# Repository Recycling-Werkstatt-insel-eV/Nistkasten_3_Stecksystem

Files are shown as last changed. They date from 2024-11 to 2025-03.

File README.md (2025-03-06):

# Vogelhaus Nr. 3

Bei diesem Vogelhaus ist der Zusammenbau ein Kinderspiel. Es werden kaum Schrauben und kein Klebstoff benötigt. Fast alle Teile werden zusammengsteckt und sind austauschbar, je nachdem welche Vogelart ihr bei euch findet. Der gesamte Entwurf besteht aus nachhaltigen und/oder recycelbaren und wiederverwendbaren Materialien. Auch der integrierte Raubtierschutz und die einfache Reinigungsmöglichkeit machen eure Vögel zu glücklichen Mieter_innen!

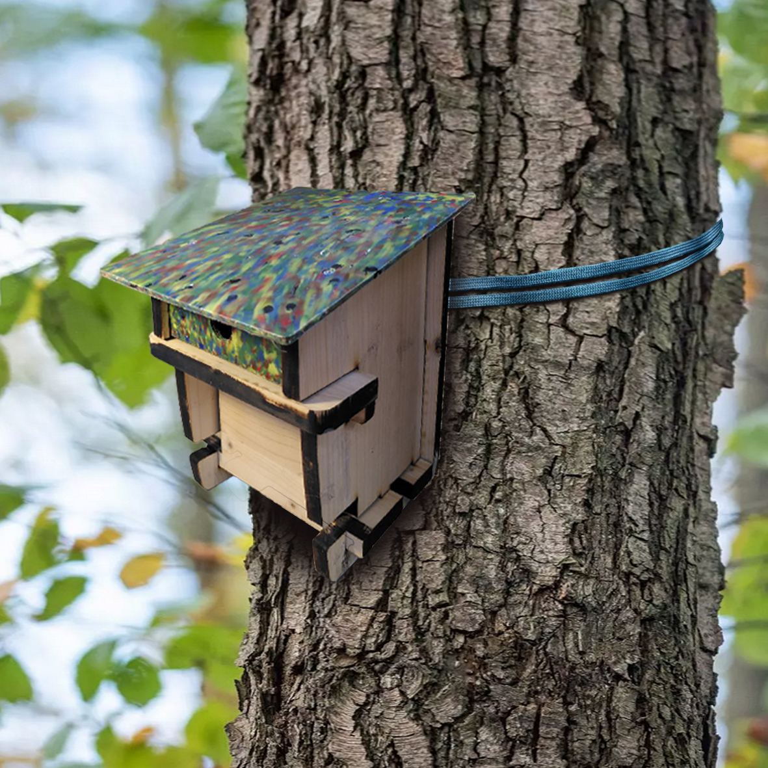
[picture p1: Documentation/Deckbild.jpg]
 

__Du möchtest dieses Vogelhaus bauen?__

Dann ist es sinnvoll, dass du dich in folgender Reihenfolge durch das Projekt manövrierst: 
Zu Beginn solltest du dir die allgemeine [Checkliste](./Documentation/Checkliste.md) anschauen um dir einen geeigneten Einstieg in das Projekt zu geben. Welche Materialien du überhaupt benötigst erfährst du in der [Materialliste](./Drawings/Materialliste_Vogelhaus_Stecksystem.pdf). Anschließend kannst du dich der [Fertigung der Einzelteile](./Documentation/Anleitung_Fertigung.md) widmen, die wenn du sie sorgsam beachtest, den [Zusammenbau](./Documentation/Anleitung_Zusammenbau.md) erleichtern wird. 
Solltest du dieses Vogelhaus noch weiterentwickeln wollen, stehen dir außerdem noch eine [CAD Datei im Step-Format](./CAD/CAD_Stecksystem_Vogelhaus.STEP) und die entsprechenden [Technischen Zeichnungen](./Drawings/Vogelhaus_Stecksystem_Technische_Zeichnungen.pdf) zur Verfügung.

# Allgemeines zum Projekt

Bei diesem Vogelhaus handelt es sich um einen von __4 Entwürfen__ aus einer Reihe innerhalb eines Projekts, in dem wir uns zur Aufgabe gemacht haben, kreative innovative und nachhaltige Ideen für Tierbehausungen zu finden und alte Lösungen zu überdenken. Unseren Fokus haben wir auf Vogelbehausungen gelegt. Und wer sind "wir"? Wir sind Menschen aus der Offenen [Recycling-Werkstatt von Insel e.V.](https://werkstatt.insel-ev.de/) in Hamburg. Besucht uns gerne auf unserer Website oder noch besser persönlich, wir freuen uns auf euch! 

Hier kommt ihr zur [Übersicht](https://github.com/Recycling-Werkstatt-insel-eV/Nistkasten_main_Uebersicht) der folgenden Entwürfe
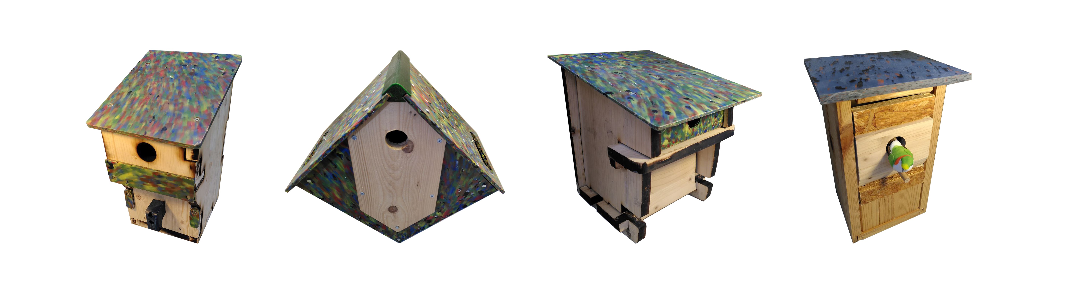
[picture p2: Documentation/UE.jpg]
 
Gefördert von der [Deutschen Stiftung Engagement und Ehrenamt](https://www.deutsche-stiftung-engagement-und-ehrenamt.de/foerderung/) haben wir im Laufe des Jahres 2024 zusammen mit Schüler_innen-Gruppen, Expert_innen vom [NABU](https://www.nabu.de/) und anderen klugen Köpfen getüftelt, wie wir Zeiten, in denen die Umwelt und Natur so schutzbedürftig wie noch nie sind, einen sinnvollen Beitrag leisten können. In Ideen- und Bau- Workshops sind dabei schlussendlich die 4 Konzepte entstanden und umgesetzt worden, die wir euch hier vorstellen wollen. 

__Und was macht unsere Entwürfe besonders?__
Besonders wichtig war uns unter anderem, dass die verwendeten Materialien möglichst nachhaltig sind und eingesetzt werden. Das heißt sie sollen wenig oder gar nicht neu produziert werden müssen. Wir wollen mit Dingen arbeiten, die es schon gibt und diese wieder aufbereiten und neu verwenden. Dafür haben wir in jedem Entwurf recycelten Kunststoff aus unserer Werkstatt verwendet. Dieser besteht aus geschredderten, geschmolzenen zu Platten gepressten Alltagsgegenständen, die sonst in den Müll gewandert wären. Außerdem sind alle Bestandtteile wieder voneinander trennbar. Es wurden keine Klebstoffe und nur wenige Schrauben verwendet. Modulare Systeme ermöglichen zusätzlich das Austauschen und ersetzen einzelner Bestandtteile, sodass die Vogelhäuser leicht repariert werden können und teilweise mehrere Funktionen und Varianten in einem Entwurf beinhalten.  

Aber wie das halt so ist... Kein Entwurf ist perfekt durchdacht. Und genau da kommt ihr ins Spiel. Wir wollen unser Projekt der Community zur Verfügung stellen und euch herzlich einladen die Vogelhäuser __nachzubauen, oder sogar weiterzuentwickeln__. Die Informationen, die  ihr genau dafür benötigt und wie ihr Schritt für Schritt vorgeht, findet ihr in den beiligenden Vogelhaus-Projekten. Von eher unkomplizierten Ideen, die mit einfachen Handwerkzeugen gefertigt werden können, bis hin zu gelaserten oder CNC- gefrästen z.T. herausfordernden Systemen ist für jede_n etwas dabei. Alles kann nichts muss und das gilt auch für die euch zur Verfügung stehenden Mittel. Von uns kommen einige gut gemeinte Ratschläge für die Umsetzung, fühlt euch jedoch gerne frei manches im Sinn eurer Möglichkeiten anders zu machen. Schaut euch gerne um ob und welches Vogelhaus etwas für euch ist, viel Spaß beim bauen und weiterdenken!

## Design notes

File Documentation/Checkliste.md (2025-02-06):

# Checkliste

Unabhängig davon ob ihr eines der Vogelhäuser nachbaut, weiterentwickelt oder einen ganz neuen Entwurf kreiren und aufhängen wollt, gibt es einige wichtige Dinge zu beachten, die für die Umwelt, die Tiere und den Erfolg des Projekts mehr oder weniger wichtig sein können. 
Hier findet ihr eine Übersicht an Checkpunkten an denen wir uns oriententiert haben. 

__Schutz vor Nesträubern__

Viele Tierarten, insbesondere Vögel sind heutzutage stark bedroht. Neben anderen Faktoren sind Nesträuber wie Waschbären, Marder und Hauskatzen dafür verantwortwortlich. Um zu verhindern, dass diese Tiere die Brut der Singvögel bedrohen gibt es bewährte Maßnahmen:

1. Gestalte die Einflugöffnung gerade so groß, dass nur der Nistvogel und vergleichbargroße Arten durchpassen.
2. Baue einen vorgezogenen Zwischenboden in das Vogelhaus, (so wie wir es z.B. bei den Vogelhäusern "Stecksystem" und "Oskar" gemacht haben).
   In dieser Form haben die Räuber Schwierigkeiten bis zur Brut hinunter zu greifen. 
4. Bringe den Vogelkasten idealerweise in einer Höhe von mindestens 2 Metern an, sodass es manchen Räubern schwerer fällt die Brut zu wittern und 
diese zu erreichen.

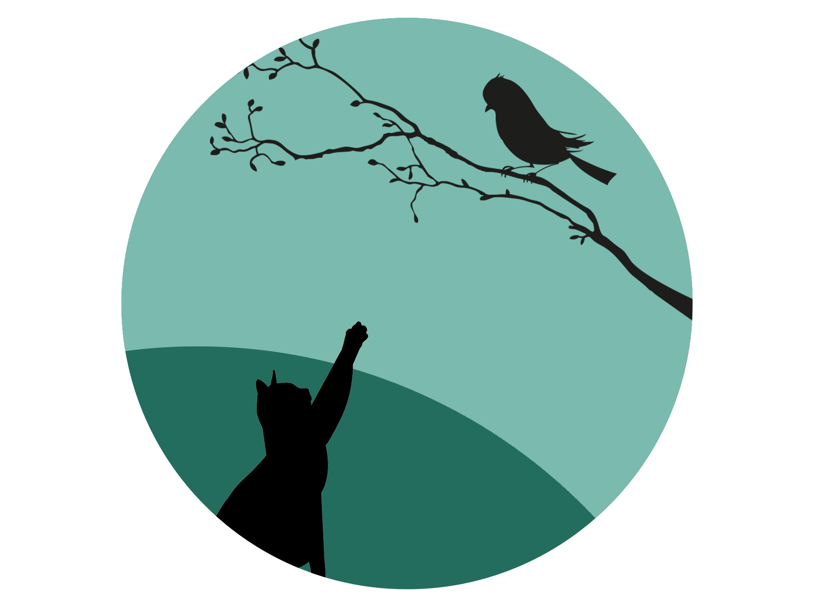
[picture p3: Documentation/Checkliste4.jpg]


__Der passende Ort__

Achte zudem darauf, dass du für dein Vogelhaus einen geeigneten Ort findest, wo sich die Tiere natürlicherweise wohl fühlen. 
Es sollte dort möglichst viel unterschiedliche Vegetation geben, die für viele Lebewesen einen Rückzugsort zum Verstecken und eine wichtige Nahrungsgrundlage bietet. Nur in einem gesunden Ökosystem siedeln sich auch Vögel an um dort zu brüten. Ich denke es sollte klar sein welches der beiden folgenden Beispiele auf dem Bild geeigneter ist.  

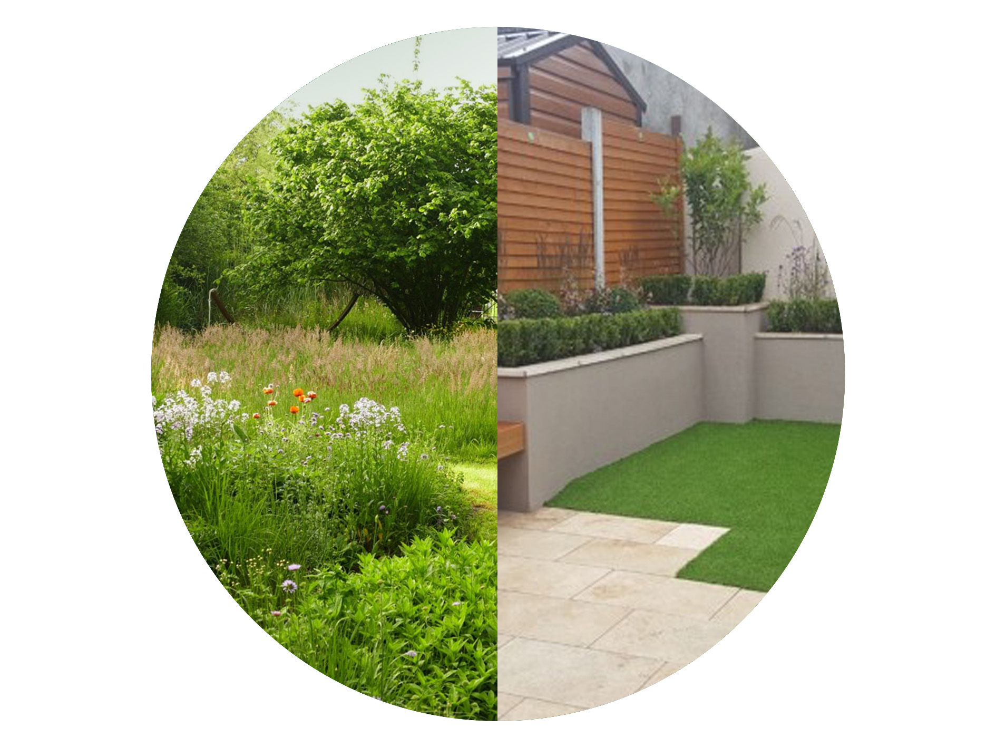
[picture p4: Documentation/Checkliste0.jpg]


__Die richtigen Maße__

Unter dem folgenden Link https://www.nabu-rlp-sued.de/artenschutz/bauanleitungen-f%C3%BCr-nisthilfen/ 
des Nabu Rheinland Pfalz findet ihr viele Infos zu dem Thema, auch die Maße für Vogelhäuser, welche sich etabliert haben um möglichst viele Vogelarten zu erreichen, indem sie gerade groß genug sind und entsprechend Material sparen. Es reicht aber wenn sie euch als ungefährer Anhaltspunkt dienen. 

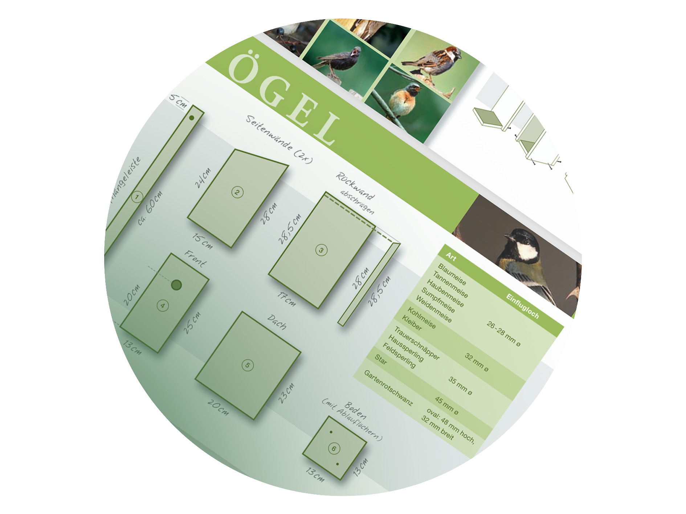
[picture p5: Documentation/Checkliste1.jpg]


__Reinigung des Nistkastens__

Leider müssen Nistkästen ein mal im Jahr nach der Brutsaison gereinigt werden, damit sie sich nicht mit Nistmaterial anfüllen und irgendwann nicht mehr bezogen werden. Gestalte den Kasten also idealerweise so, dass er sich unkompliziert öffnen und reinigen lässt. Die Brutsaison der meisten Singvögel ist im Frühsommer von Mai bis Juli. Ab August lohnt sich der erste Blick ins Innere ob der Mieter mitlerweile ausgezogen ist. 

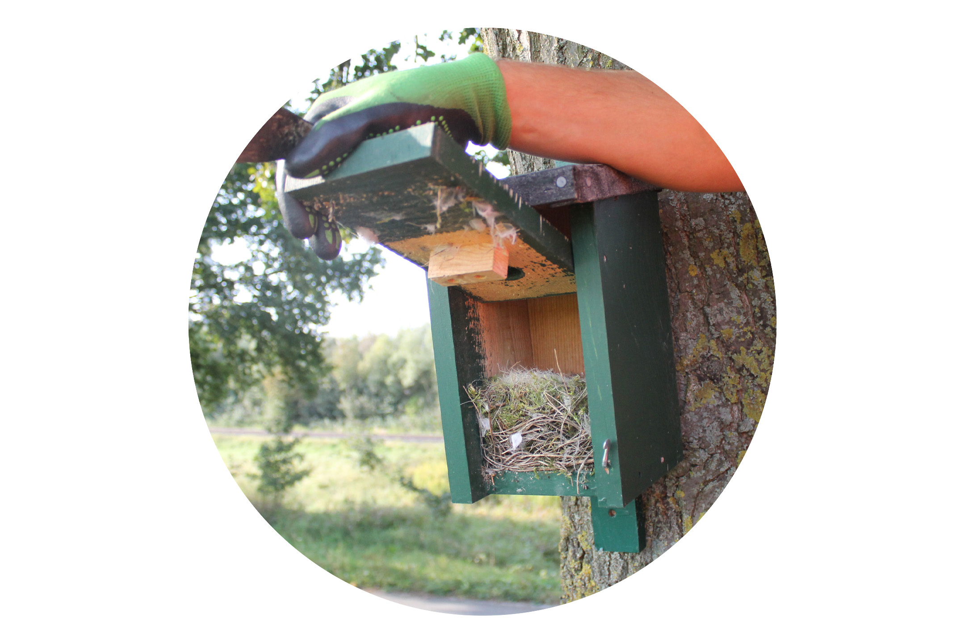
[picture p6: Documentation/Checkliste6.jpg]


__Die ideale Befestigung__

Einfache Eisen- oder Kupfernägel können für einige Baumarten problematisch sein, da sie für diese in einigen Fällen gesundheitsschädlich sind und der Pflanze schaden. Zudem gehen Werkzeuge wie Kettensägen beim Fällen der Bäume kaputt wenn sie in hartes Metall sägen. Um dies zu verhindern ist es ratsam Aluminium-Nägel zu verweden.   

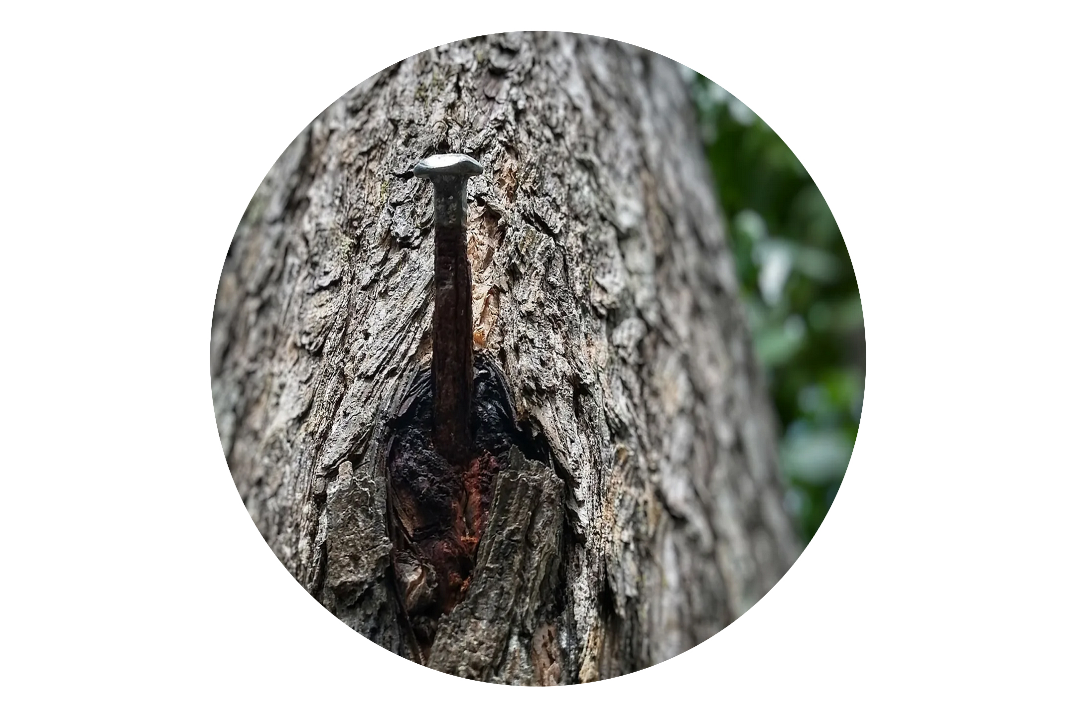
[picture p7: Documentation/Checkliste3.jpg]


__Geeignetes Material__

Die Materialwahl der Tierbehausung ist gleich aus mehreren Gründen besonders wichtig. Beachte dabei bitte folgende Punkte: 

1. Das Material sollte möglichst atmungsaktiv sein, denn wenn das Innere des Hauses mal nass wird und nicht richtig trocknet, kann sich Schimmel bilden, es setzen Fäulnisprozesse ein und Parasiten haben bei den Nestlingen leichteres Spiel. Das schadet der Gesundheit der Brut und verkürzt zudem die Langlebigkeit der Behausung.
2. Achte darauf, dass die verwendeten Materialien nicht vorbehandelt oder beschichtet wurden. In vielen Fällen verstecken sich giftige und umweltschädliche Chemikalien in und auf wiederverwerteten Gegenständen.
3. Denke an die Nachhaltigkeit deiner Materialien. Nachhaltig ist ein Material z.B. dann, wenn es sich mit der Zeit durch die äußeren Einflüsse natürlich zersetzt und komplett wieder in den biologischen Stoffkreislauf zurückgeführt werden kann. Versuche zudem möglichst keine neuen Materialien zu verwenden, sondern bereits existierende Werkstoffe neu aufzubereiten und wiederzuverwenden. Das klappt nicht immer, aber in vielen Fällen. Auch recycelter Kunststoff ist in eingen Fällen deutlich nachhaltiger als manche anderen Alternativen. Bspw. unsere Dächer bestehen aus wasserabweisendem Kunststoff um die Lebensdauer der Behausungen zu verlängern. 

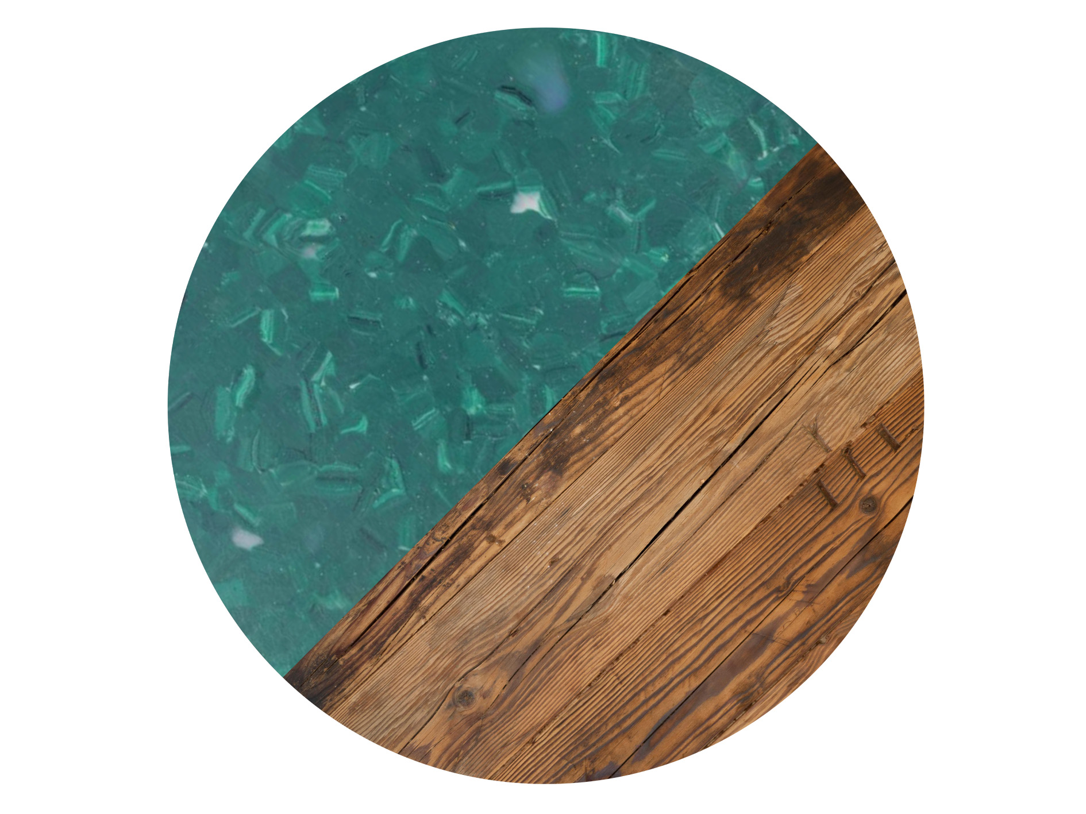
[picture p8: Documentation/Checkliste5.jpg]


Wenn du möglichst viele dieser Punkte beachtest, hast du in deinem Vorhaben schon halb gewonnen.

__Viel Spaß bei der Umsetzung!__

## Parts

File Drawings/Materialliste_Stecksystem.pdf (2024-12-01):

Materialliste Vogelhaus "Stecksystem"

Bezeichnung | Material | Anzahl | Maße/Typus | Beschreibung/Anmerkungen
Rohling Holzbrett | Massivholz aus Fichte, Kiefer, Lärche oder vergleichbarem Nadelholz vorzugsweise Altholz oder eine andere nachhaltige Alternative. | Min. 1 | 820/400/18 mm | Die Maße beziehen sich auf die Annahme, dass alle Holzteile aus einem Stück gelasert werden. (siehe Laservorlage Holzteile) Das Längen- und Breitenmaß kann variieren, wenn die Laserschnitte aufgeteilt werden oder eine andere Ausschnittmethode gewählt wird. Die Dicke sollte maximal um 1 mm variieren.
Rohling Kunststoffteile | Kunststoff z.B. PE (Polyethylen) oder PP (Polypropylen) möglichst aus nachhaltiger Herstellung/ Weiterverwendung | Min. 1 | 580/250/10 mm | Die Kunststoffteile können gelasert werden, (siehe Laservorlage Kunststoffteile) zu beachten ist jedoch eine mögliche Ausgasung die gesundheittschädlich sein kann. Beachten sie bitte die Sicherheitsvorschriften. Alternativ können die Teile auch gesägt und gebohrt werden.
Schrauben | Metall (Stahl oder Messing gerne verzinkt oder veredelt um die Langlebigkeit zu gewährleisten) | 4 | Typ M3 Durchmesser: 3 mm Läne: 20-25 mm | Die Schrauben dienen der Dachbefestigung.
Schnüre | Kunst- oder Naturfaser z.B. PE oder PP, je nach Nachhaltigkeit und Langlebigkeit vorausgesetzt hohe Zugfestigkeit und Wetterbeständigkeit. | 2 | jw. min. 200 mm Länge, 3-10 mm Durchmesser | Wird das Vogelhaus an einem Baum befestigt ist zu beachten, dass die Schnüre am Baum festwachsen oder von zunehmender Spannung zerstört werden können. Hier bieten sich stattdessen ein dehnbareres Material oder alternativ Nägel an.

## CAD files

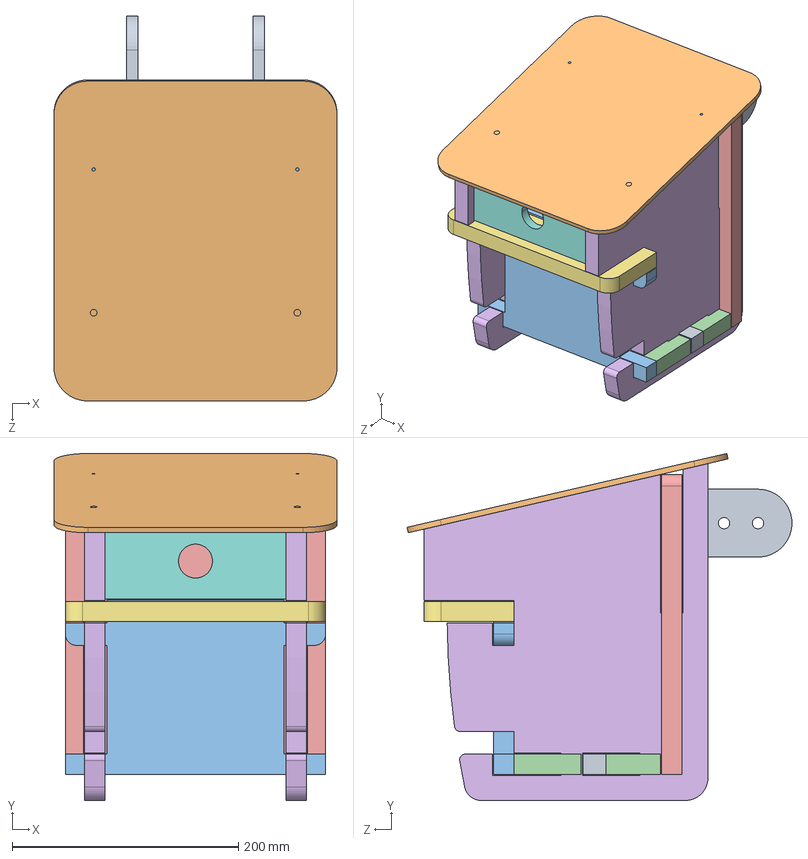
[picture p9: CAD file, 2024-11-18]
CAD/CAD_Stecksystem_Vogelhaus.STEP
250.0 x 306.5 x 340.1 mm

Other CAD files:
3D_printing/CAD_Stecksystem_Vogelhaus.STL

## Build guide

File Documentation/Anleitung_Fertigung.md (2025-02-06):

# Anleitung zur Fertigung der einzelnen Bauteile

Hier und im folgenden ist beschrieben wie beim Bau von Vogelhaus "Stecksystem" idealerweise vorgegangen werden kann. Ergänzende Infos und Kaufvorschläge der Materialien sind in der [Materialliste](../Drawings/Materialliste_Stecksystem.pdf) zu finden. Alle Komponenten dieses Vogelhauses lassen sich mit Hilfe eines Industrielasers ausschneiden, sofern dieser eine Materialstärke von 18 mm durch Weichholzarten wie Kiefer oder Fichte bewerkstelligen kann. 

__Fertigung Kunststoffteile__

Unter diesem Link findest du die [Laservorlage für die Kunststoffteile](../Drawings/Stecksystem_Laservorlage_Kunststoffteile.svg) Alle Kunststoffkomponenten können aus einem einzelnen Werkstück der Mindestgröße 250/580/10 mm gelasert werden. Die Vektorgrafiken können auch separat ausgeschnitten werden, zu beachten ist jedoch die Dicke des Werkstücks von 10 mm (+- 0.5 mm) Alternativ zu Kunststoff können die Teile auch wie im folgenden aus Holz gearbeitet werden. Es sind 4 verschiedene Größen von Einfluglöchern der Frontplatte mit den Maßen 25, 30, 32 und 40 mm für verschiedene Vogelarten in der Grafik angelegt worden.  
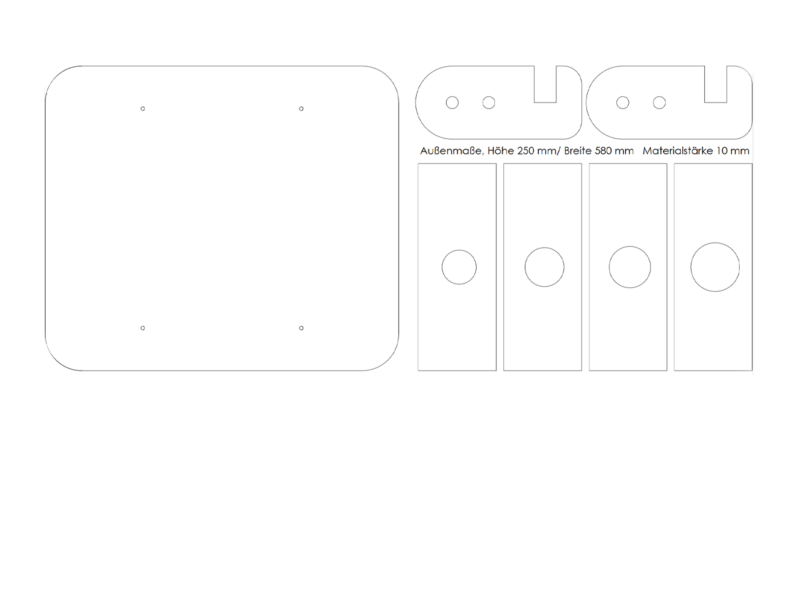
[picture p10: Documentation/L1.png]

__Fertigung Holzteile__

Unter folgendem Link findest du die  [Laservorlage für die Holzteile](../Drawings/Stecksystem_Laservorlage_Holzteile.svg) Alle Holzteile können aus einem einzelnen Werkstück der Mindestgröße 820/400/18 mm gelasert werden. Die Vektorgrafiken können auch separat ausgeschnitten werden, zu beachten ist jedoch die Dicke des Werkstücks von 18 mm (+- 0.5 mm)  
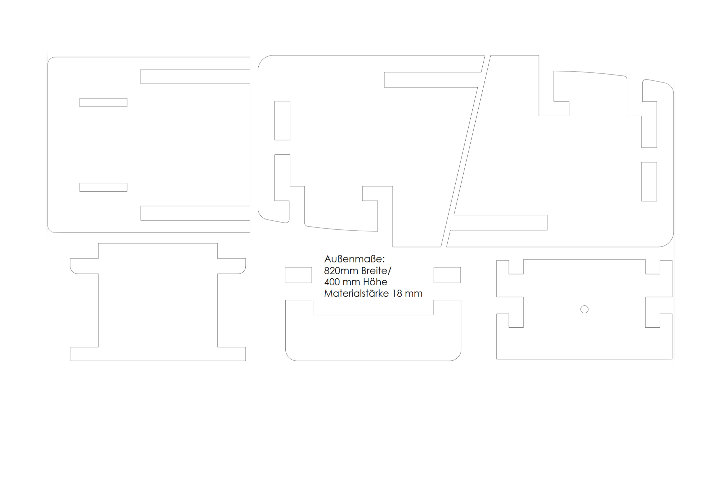
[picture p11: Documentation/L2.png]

Für den Fall, dass kein Laser zur Bearbeitung der Koponenten zur Verfügung steht oder das nötige Fachwissen nicht vorhanden ist, lassen sich die Teile auch händisch mit anderen Subtraktionsverfahren herstellen. Auch CNC Fräsen ist eine Option. Für diesen Fall wurdem im Ordner "Drawings" technische Zeichnungen mit den Maßen der Komponenten abgelegt. Von diesen Alternativen ist aufgrund der der komplizierten Geometrie der Teile jedoch eher abzuraten.

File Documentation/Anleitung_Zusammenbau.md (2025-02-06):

# Aufbauanleitung

Hier findet ihr die Bauanleitung von Vogelhaus "Stecksystem". Achtet darauf, dass ihr alle entsprechenden Einzelteile im Voraus gefertigt habt, bevor ihr versucht die Teile zusammenzusetzen. Die Reihenfolgenach dem folgenden Prinzip ist bindend damit der Zusammenbau einfach und fehlerfrei abläuft. Bei diesem Entwurf ist es besonders wichtig, dass du vorsichtig vorgehst und keine Teile mit Gewalt einfügst, damit beim Holz keine Ecken abbrechen. 

__Benötigte Werkzeuge und Hilfsstoffe für den Zusammenbau__

1. Schraubendreher oder Akkuschrauber
2. Schraubzwingen oder eine helfende Person
3. Schleifpapier (Körnung 80-200) oder Holzpfeilen für Korrekturen oder abschließende Schönheitsarbeiten.

__Schritt 1__ Setze die hölzernen Seitenände mit dem Boden zusammen. Hierfür musst du das Bodenteil nach dem anstecken der Wände nach hinten drücken!
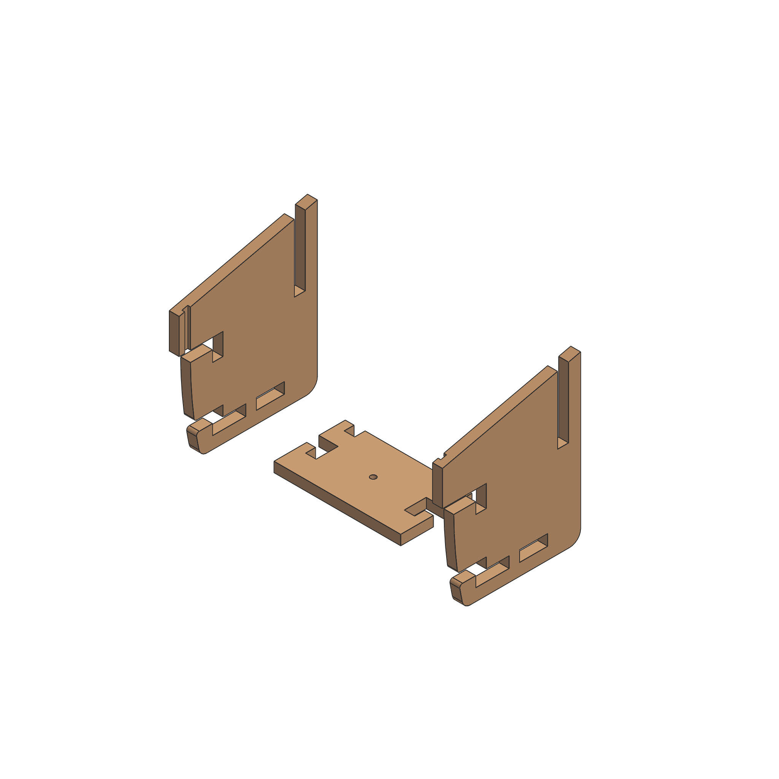
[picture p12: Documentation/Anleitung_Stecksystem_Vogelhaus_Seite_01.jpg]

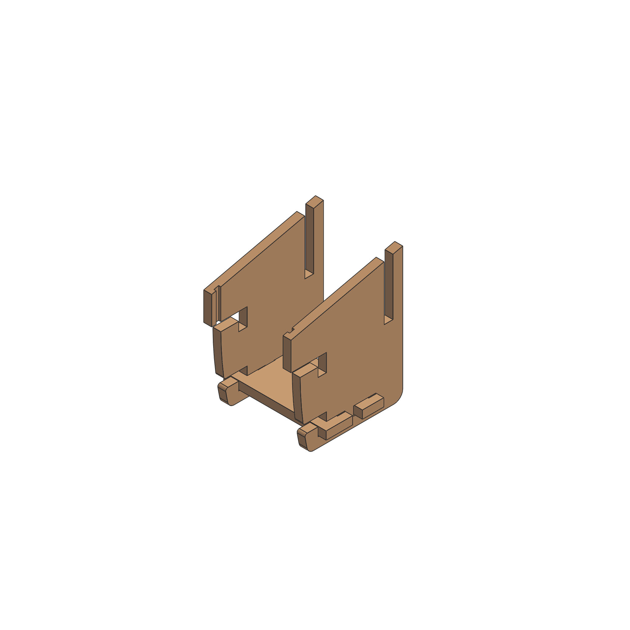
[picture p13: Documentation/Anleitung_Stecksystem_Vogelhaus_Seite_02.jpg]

__Schritt 2__ Nun schiebe folgendermaßen von oben die Rückwand ein. 
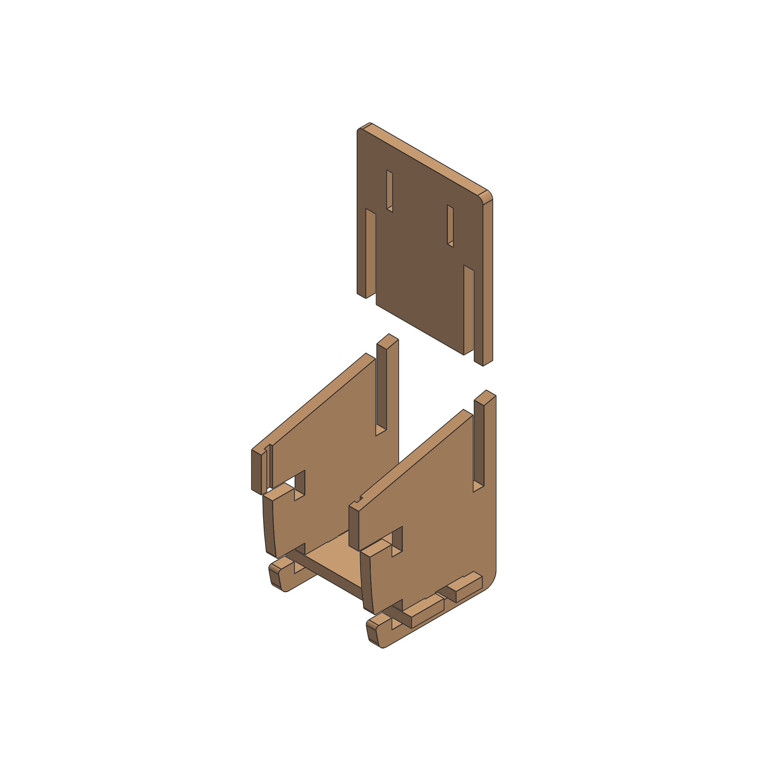
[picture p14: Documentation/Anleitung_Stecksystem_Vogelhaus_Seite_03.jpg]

__Schritt 3__ Anschließend schiebe von vorne die Frontwand in das Gebilde bis zum Anschlag, sodass sie automatisch nach unten einrastet. Gegebenfalls musst du die Vorderwand leicht nach unten drücken.
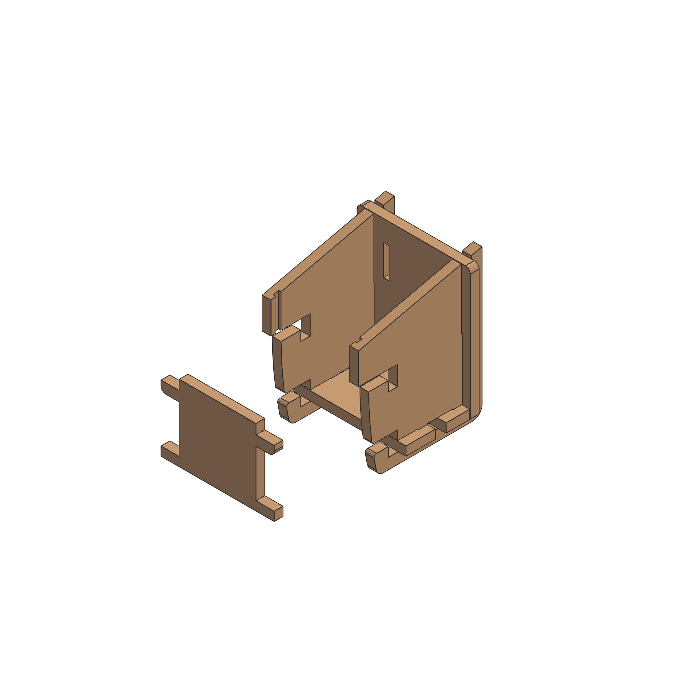
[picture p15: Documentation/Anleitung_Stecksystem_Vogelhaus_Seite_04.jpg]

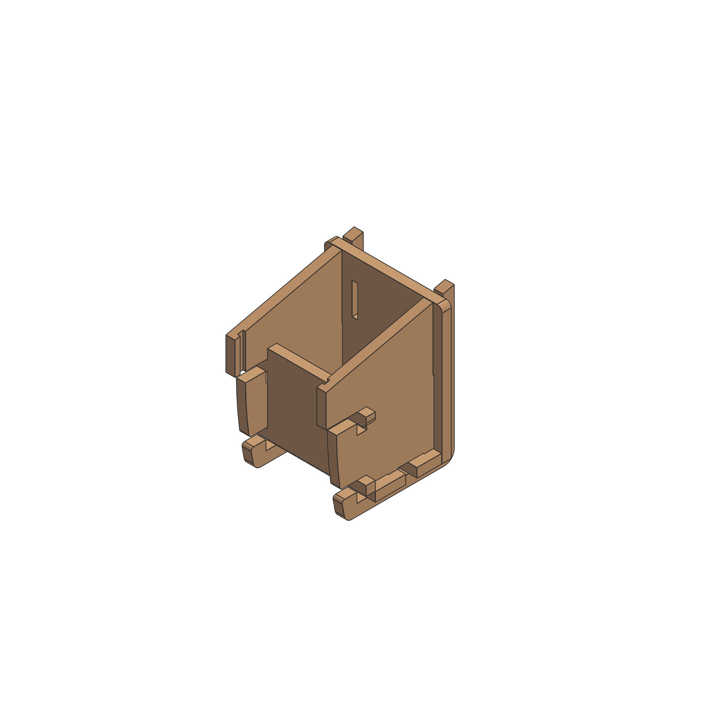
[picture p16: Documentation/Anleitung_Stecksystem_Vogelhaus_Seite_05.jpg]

__Schritt 4__ Nun schiebe frontal den Zwischenboden ein. Alle Holzteile sind nun verbaut. 
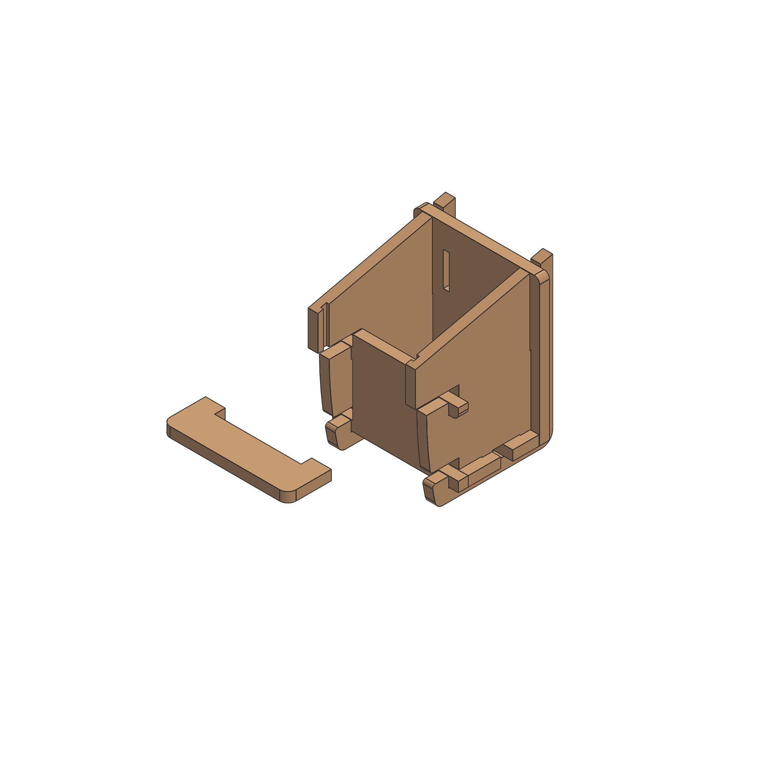
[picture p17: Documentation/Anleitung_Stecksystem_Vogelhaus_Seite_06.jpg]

__Schritt 5__ Jetzt wird von oben die Frontplatte aus Kunstoff eingeschoben. (Je nachdem für welche Vogelart du dich entscheiden hast)
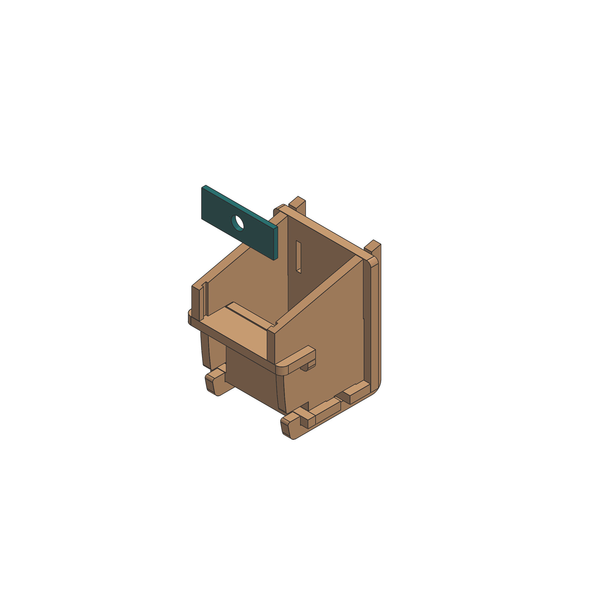
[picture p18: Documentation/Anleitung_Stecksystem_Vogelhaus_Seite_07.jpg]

__Schritt 6__ Abschließend muss nur noch das Dach angeschraubt werden. Verwende hierfür die 4 Schrauben der Größe M3 mit 20-22 mm Länge. 
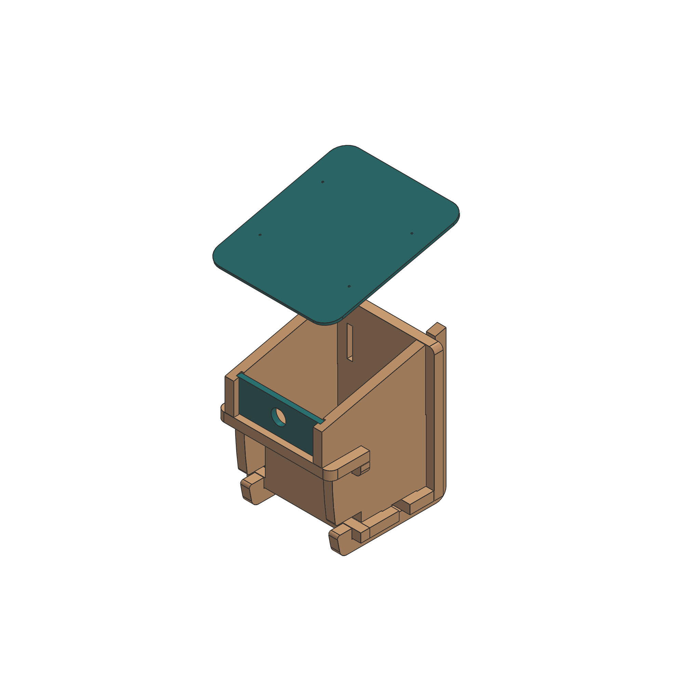
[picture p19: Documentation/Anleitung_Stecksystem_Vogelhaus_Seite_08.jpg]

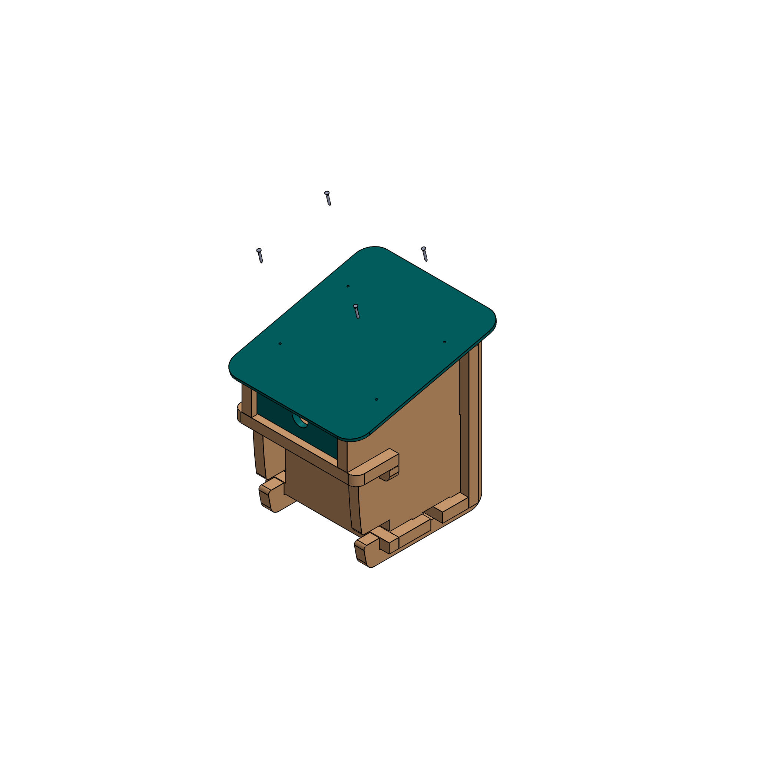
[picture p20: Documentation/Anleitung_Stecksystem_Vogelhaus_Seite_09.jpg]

__Schritt 7__ Hänge nun die Montage-Haken in die Rückwand ein. 
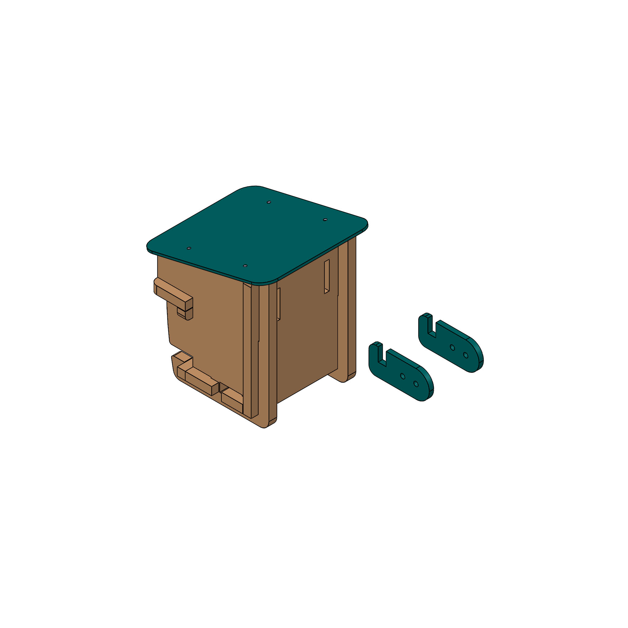
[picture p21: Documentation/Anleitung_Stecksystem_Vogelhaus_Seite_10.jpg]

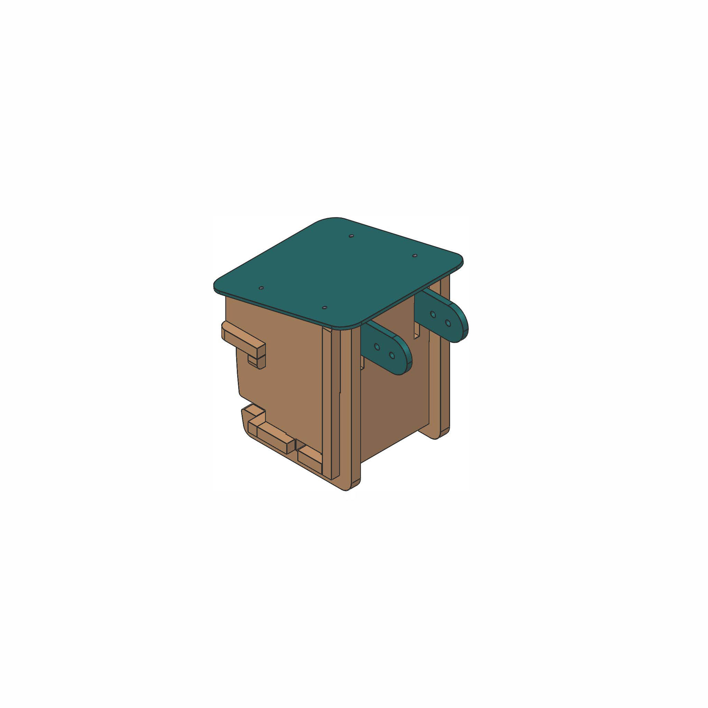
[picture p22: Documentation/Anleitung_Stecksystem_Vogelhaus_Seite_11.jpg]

__Fertig__. Nun kann das Vogelhaus aufgehängt werden. Jenachdem für welchen Ort du dich entschieden hast, verwende hierfür jenachdem wofür du dich entschieden hast Kunst- oder
Naturfaser z.B. PE oder PP, je nach Nachhaltigkeit und Langlebigkeit vorausgesetzt hohe Zugfestigkeit und Wetterbeständigkeit. 

__Austausch des Einfluglochs__
Beachte, dass du durch das Hervorziehen des Zwischenbodens die Frontplatte nach unten herausziehen und austauschen kannst ohne das Dach abnehnen zu müssen. Dies ist sinnvoll, wenn du die Einfluglochgröße den angesprochenen Vogelarten anpassen willst.  
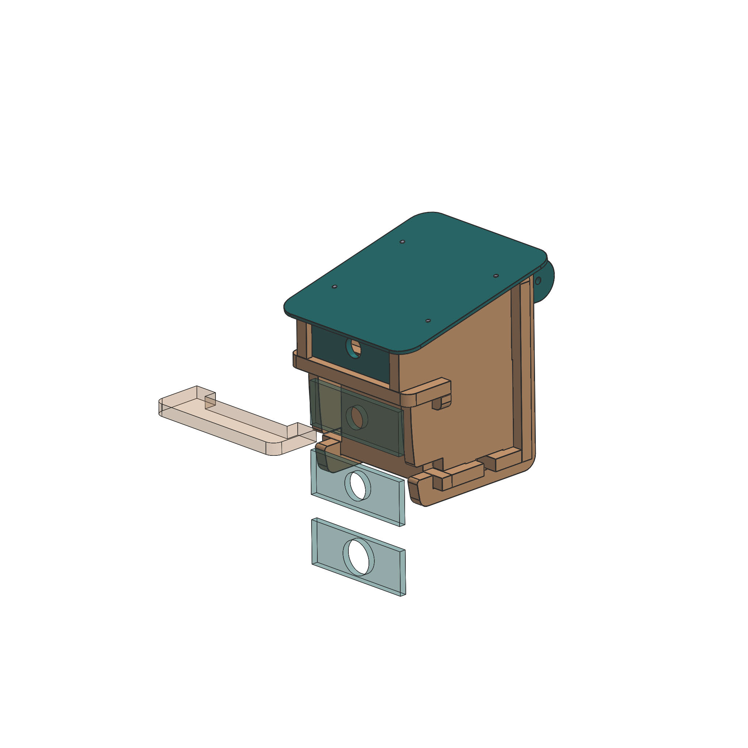
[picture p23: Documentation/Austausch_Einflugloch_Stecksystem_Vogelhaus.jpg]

__Austausch der Frontplatte__
Auch die Frontplatte lässt sich auf dieses Weise unkompliziert herausnehmen um das Vogelhaus unkompliziert reinigen zu können. 
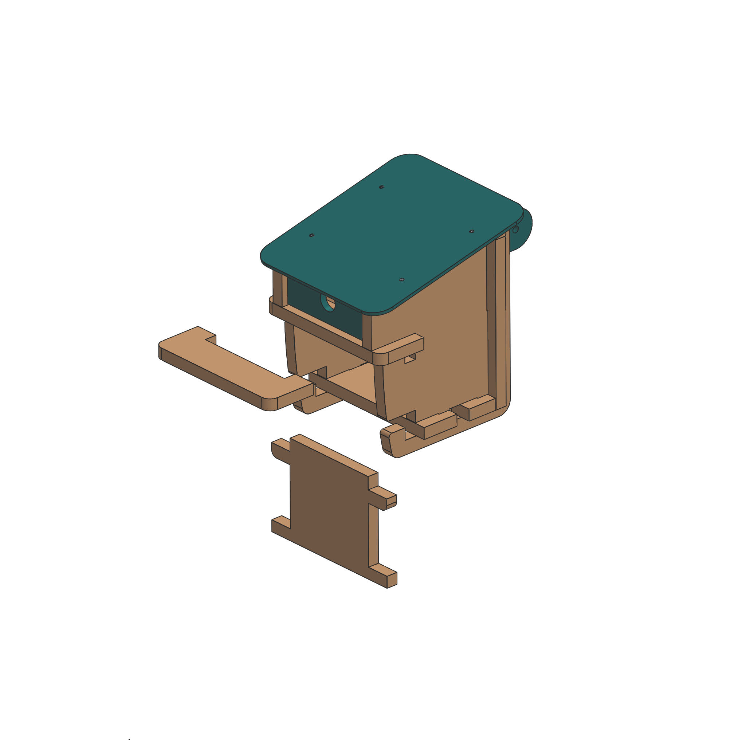
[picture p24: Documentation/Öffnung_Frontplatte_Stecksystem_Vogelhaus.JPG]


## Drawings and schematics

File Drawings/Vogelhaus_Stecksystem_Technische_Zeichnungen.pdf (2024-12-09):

E | E
F | F

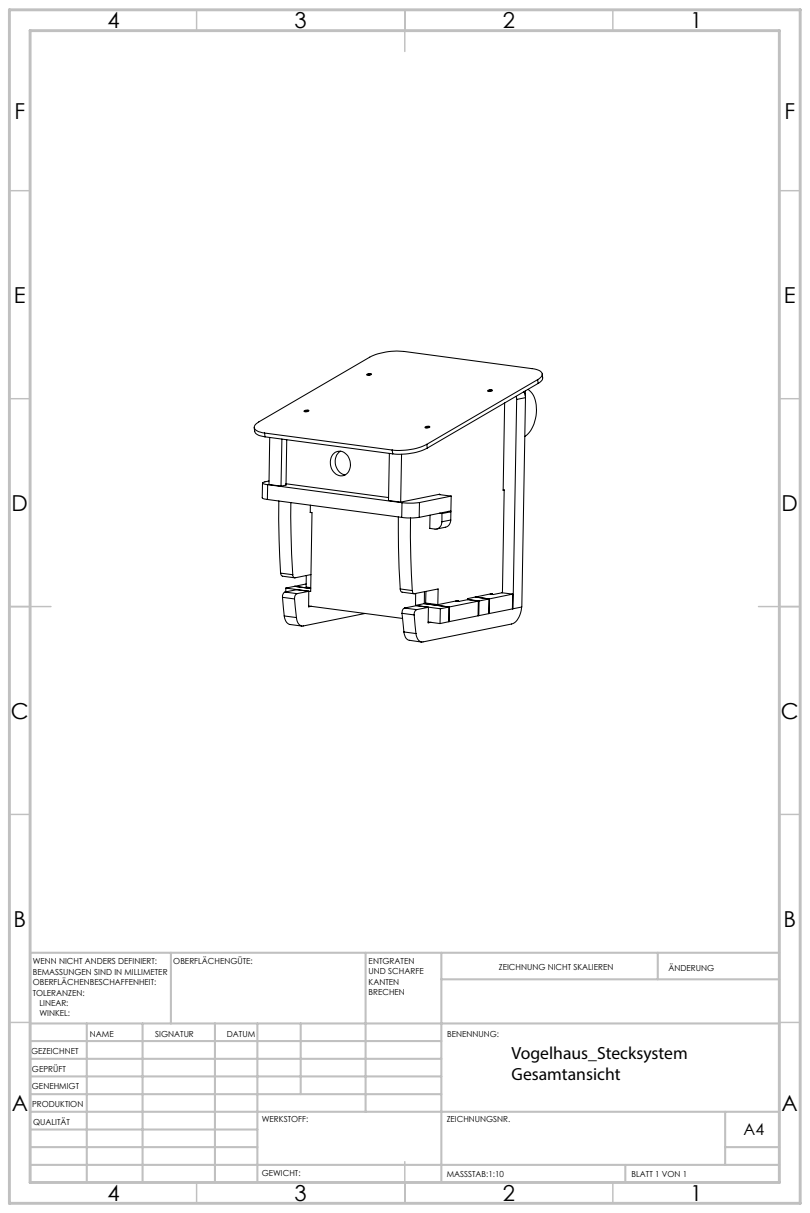
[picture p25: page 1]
GEWICHT:; MASSSTAB:1:10; BLATT 1 VON 1; ZEICHNUNG NICHT SKALIEREN; ÄNDERUNG; ENTGRATEN UND SCHARFE KANTEN BRECHEN; WENN NICHT ANDERS DEFINIERT:; OBERFLÄCHENGÜTE:

BEMASSUNGEN SIND IN MILLIMETER
OBERFLÄCHENBESCHAFFENHEIT:
TOLERANZEN:
LINEAR:
WINKEL:

NAME | SIGNATUR | DATUM | | | | BENENNUNG: Vogelhaus_Stecksystem Gesamtansicht
GEZEICHNET
GEPRÜFT
GENEHMIGT
PRODUKTION
QUALITÄT | | | | WERKSTOFF: | ZEICHNUNGSNR. | A4

E | E
F | F

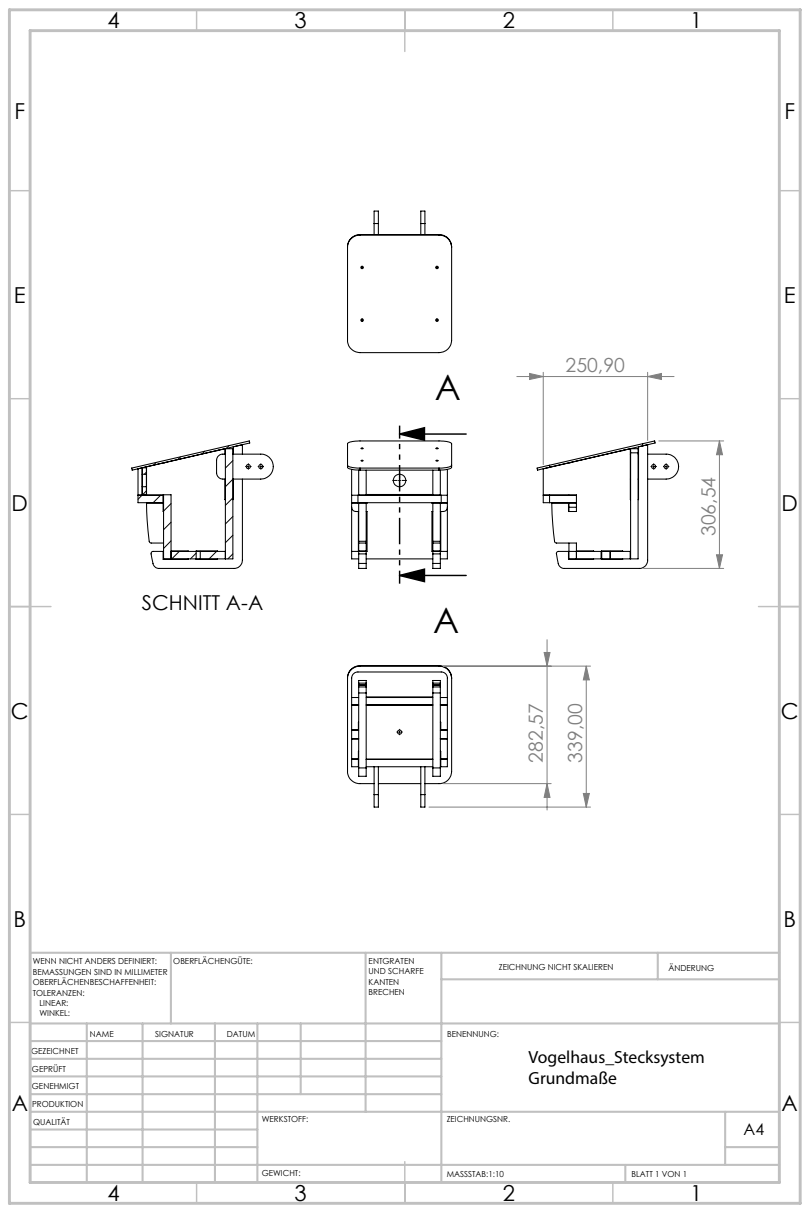
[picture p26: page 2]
SCHNITT A-A; ZEICHNUNG NICHT SKALIEREN; ÄNDERUNG; ENTGRATEN UND SCHARFE KANTEN BRECHEN; WENN NICHT ANDERS DEFINIERT:; OBERFLÄCHENGÜTE:

BEMASSUNGEN SIND IN MILLIMETER
OBERFLÄCHENBESCHAFFENHEIT:
TOLERANZEN:
LINEAR:
WINKEL:

NAME | SIGNATUR | DATUM | BENENNUNG: Vogelhaus_Stecksystem Grundmaße
GEZEICHNET
GEPRÜFT
GENEHMIGT
PRODUKTION

# Einflugloch

E | E

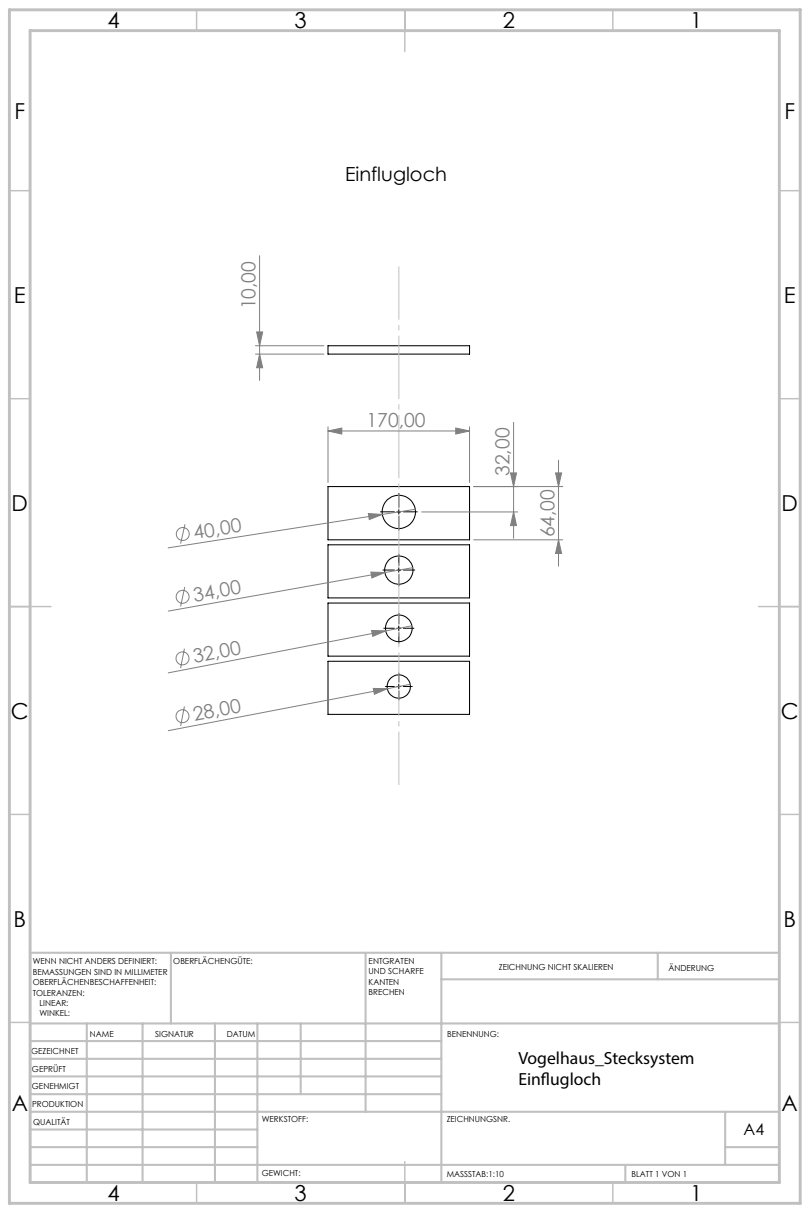
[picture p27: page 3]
ZEICHNUNG NICHT SKALIEREN; ÄNDERUNG; ENTGRATEN UND SCHARFE KANTEN BRECHEN; WENN NICHT ANDERS DEFINIERT:; OBERFLÄCHENGÜTE:

BEMASSUNGEN SIND IN MILLIMETER
OBERFLÄCHENBESCHAFFENHEIT:
TOLERANZEN:
LINEAR:
WINKEL:

NAME | SIGNATUR | DATUM | BENENNUNG: Vogelhaus_Stecksystem Einugloch
GEZEICHNET
GEPRÜFT
GENEHMIGT
PRODUKTION

E | E
F | F

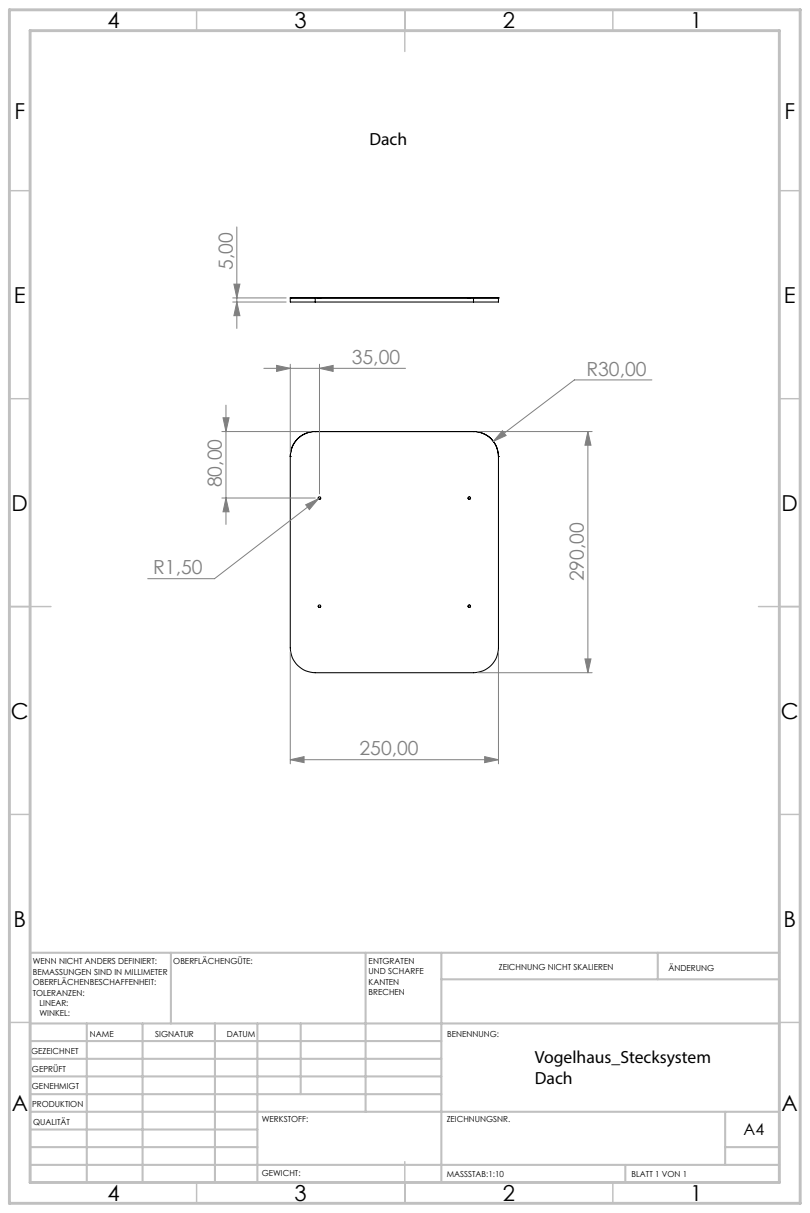
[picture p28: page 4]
ZEICHNUNG NICHT SKALIEREN; ÄNDERUNG; ENTGRATEN UND SCHARFE KANTEN BRECHEN; WENN NICHT ANDERS DEFINIERT:; OBERFLÄCHENGÜTE:; Dach

BEMASSUNGEN SIND IN MILLIMETER
OBERFLÄCHENBESCHAFFENHEIT:
TOLERANZEN:
LINEAR:
WINKEL:

NAME | SIGNATUR | DATUM | BENENNUNG: Vogelhaus_Stecksystem Dach
GEZEICHNET
GEPRÜFT
GENEHMIGT
PRODUKTION

# Haken

E | E

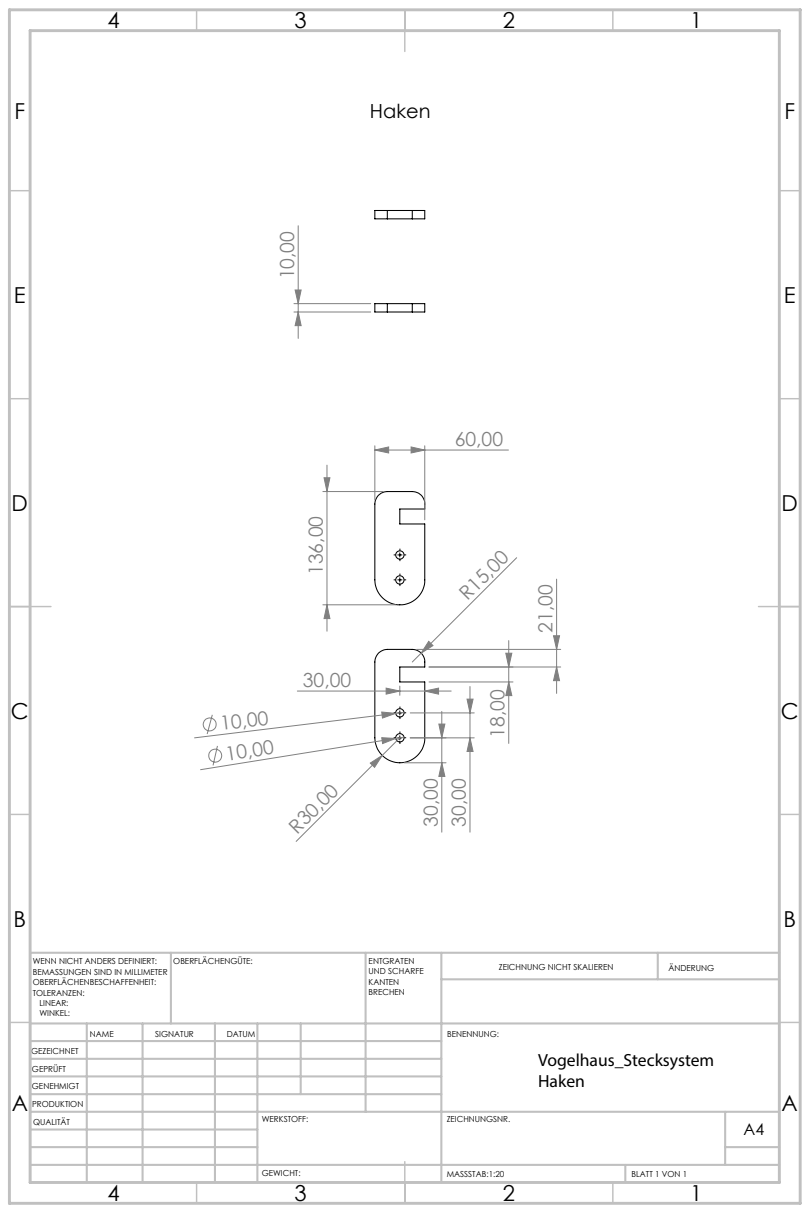
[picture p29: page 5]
MASSSTAB:1:20; BLATT 1 VON 1; ZEICHNUNG NICHT SKALIEREN; ÄNDERUNG; ENTGRATEN UND SCHARFE KANTEN BRECHEN; WENN NICHT ANDERS DEFINIERT:; OBERFLÄCHENGÜTE:

BEMASSUNGEN SIND IN MILLIMETER
OBERFLÄCHENBESCHAFFENHEIT:
TOLERANZEN:
LINEAR:
WINKEL:

NAME | SIGNATUR | DATUM | BENENNUNG: Vogelhaus_Stecksystem Haken
GEZEICHNET
GEPRÜFT
GENEHMIGT
PRODUKTION

250,00

# Seitenwände

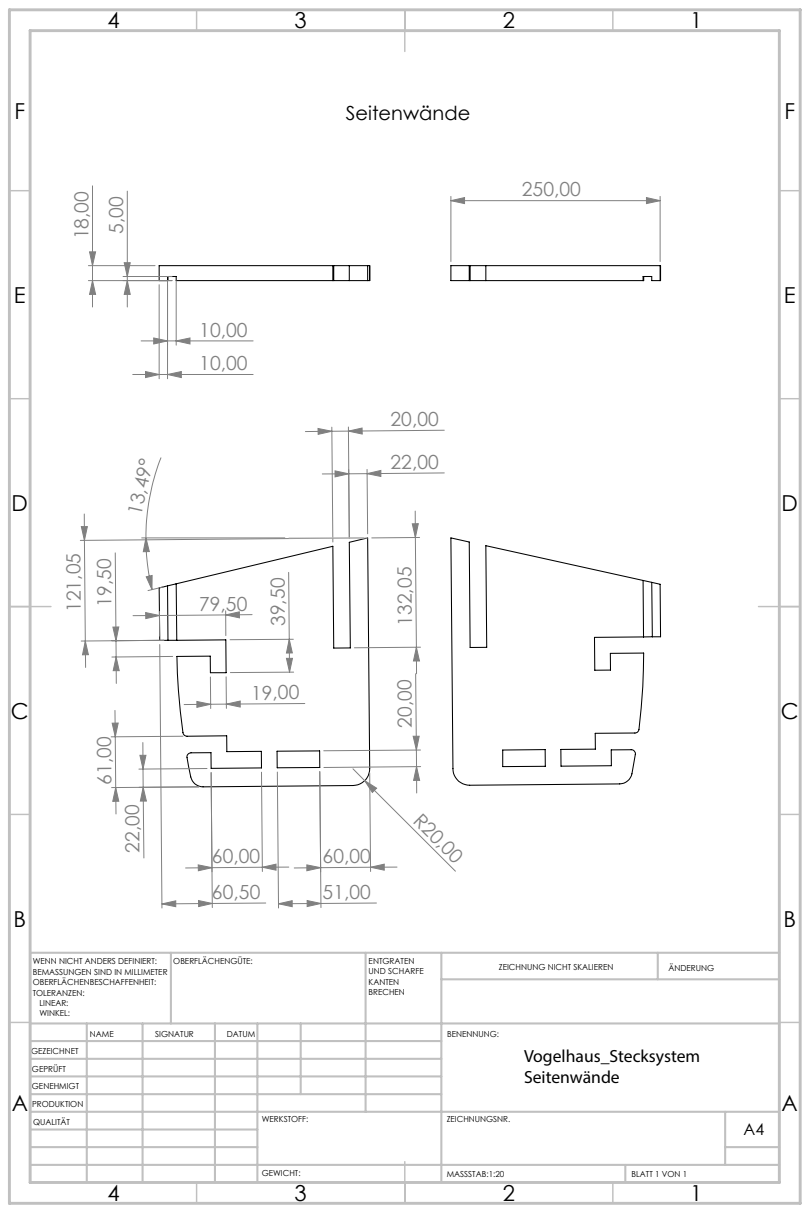
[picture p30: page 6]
ZEICHNUNG NICHT SKALIEREN; ÄNDERUNG; ENTGRATEN UND SCHARFE KANTEN BRECHEN; WENN NICHT ANDERS DEFINIERT:; OBERFLÄCHENGÜTE:

BEMASSUNGEN SIND IN MILLIMETER
OBERFLÄCHENBESCHAFFENHEIT:
TOLERANZEN:
LINEAR:
WINKEL:

NAME | SIGNATUR | DATUM | BENENNUNG: Vogelhaus_Stecksystem Seitenwände
GEZEICHNET
GEPRÜFT
GENEHMIGT
PRODUKTION

230,00
154,00

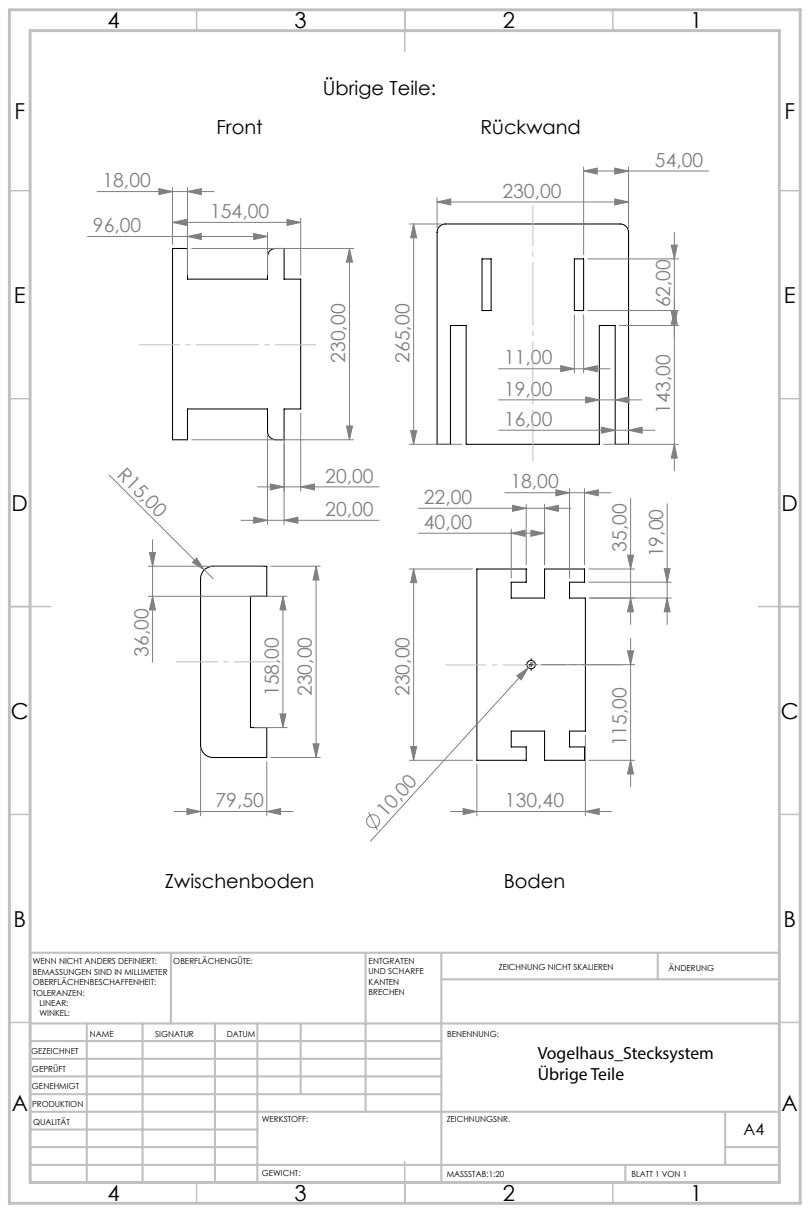
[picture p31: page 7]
Front; Zwischenboden; Boden; Übrige Teile:; Rückwand; ZEICHNUNG NICHT SKALIEREN; ÄNDERUNG; ENTGRATEN UND SCHARFE KANTEN BRECHEN; WENN NICHT ANDERS DEFINIERT:; OBERFLÄCHENGÜTE:

BEMASSUNGEN SIND IN MILLIMETER
OBERFLÄCHENBESCHAFFENHEIT:
TOLERANZEN:
LINEAR:
WINKEL:

NAME | SIGNATUR | DATUM | BENENNUNG: Vogelhaus_Stecksystem Übrige Teile
GEZEICHNET
GEPRÜFT
GENEHMIGT
PRODUKTION
